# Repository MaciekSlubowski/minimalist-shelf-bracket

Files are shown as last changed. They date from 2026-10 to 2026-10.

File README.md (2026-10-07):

Minimalist Shelf Bracket

A sleek, fully parametric 3D-printable wall mount for shelves. Written in OpenSCAD, this minimalist bracket features a smooth geometric arch, clean lines, and a topology-inspired design optimized for flat, support-free FDM printing. It combines modern aesthetics with high structural integrity.
## 📷 Gallery

<p align="center">
  Assembled Shelves System
  Mounted Bracket Close-up
</p>
<p align="center">
  <i>Left: The brackets mounted on a solid wall, seamlessly supporting wooden shelf boards. Right: Close-up of the flush fit and sleek arch supporting the shelf.</i>
</p>

<p align="center">
  Printed Bracket on Table
  Cura Slicer View
</p>
<p align="center">
  <i>Left: The printed bracket showing clean layer lines and perfectly formed countersunk holes. Right: Slicer visualization demonstrating the flat, support-free print orientation.</i>
</p>

📏 Default Dimensions

Based on the default parameters in the OpenSCAD file, the generated bracket has the following specifications:

Shelf Arm (X-axis): 210 mm

Wall Arm (Y-axis): 100 mm

Frame Width: 12 mm

Total Thickness: 20 mm

Mounting Holes: Countersunk, designed for standard flat-head screws to sit completely flush with the surface.

✨ Features

Fully Parametric: Easily adjust arm lengths, frame width, arch thickness, and overall depth directly in the OpenSCAD file to fit any shelf size.

Support-Free Printing: Carefully designed to be printed completely flat on the build plate. Requires zero support structures, saving material and post-processing time.

Sleek & Minimalist: Relies on simple, unobtrusive geometry that blends perfectly into modern, Scandinavian, or industrial interiors.

## ⚙️ Key OpenSCAD Variables

The bracket is fully customizable. You can easily adapt the geometry to your specific needs by modifying the following variables at the top of the `.scad` file:

*   **`shelf_len`** (Default: `210`): The length of the horizontal arm supporting the shelf (along the X-axis).
*   **`wall_len`** (Default: `100`): The length of the vertical arm mounted to the wall (along the Y-axis).
*   **`arm_width`** (Default: `12`): The width of the solid outer frame. This determines the main structural rigidity of the bracket.
*   **`arch_thick`** (Default: `6`): The thickness of the inner geometric arch. Kept thinner than the main frame to maintain a sleek, visually lightweight aesthetic.
*   **`thickness`** (Default: `20`): The total 3D depth (Z-axis) of the printed bracket.
*   **`$fn`** (Default: `150`): The resolution parameter. Set high to ensure the geometric curves and countersunk holes render perfectly smooth.

## 🔧 Pro-Tip: Fixing Misaligned Drill Holes

Did your drill bit slip on the masonry, leaving the holes in your wall slightly too high or too low? Don't drill new holes and ruin your wall! You can easily shift the mounting holes directly on the 3D model to perfectly match the mistake on your wall. 

Just scroll down to **STEP 4: FINAL 3D MODEL GENERATION** in the OpenSCAD code and adjust the coordinates passed to the hole functions:
*   `wall_hole(-85);` ➔ Change the `-85` (Y-axis) to move the hole up or down along the wall arm.
*   `shelf_hole(170);` ➔ Change the `170` (X-axis) to shift the shelf mounting hole left or right.

🖨️ Recommended Print Settings

To ensure the bracket can safely support loads (like thick wooden boards and books) without snapping, follow these guidelines

Material: PETG or PETG-CF (Carbon Fiber) works best for superior layer adhesion, impact resistance, and slight flexibility under load. 

Layer Height: 0.20 mm - 0.24 mm. While a 0.8 mm nozzle can print thicker layers, keeping it around 0.24 mm ensures the curved organic arch remains smooth and aesthetically pleasing.

Walls/Perimeters: 4-5 walls. This is CRITICAL. The structural strength of a bracket comes primarily from its thick outer perimeters, not the infill.

Top/Bottom Thickness: ~1.4 mm (approx. 5-8 layers depending on your layer height) to ensure solid mounting points.

Infill: 20% - 25% Gyroid. The 3D gyroid pattern distributes stress evenly across all axes, perfectly complimenting the topology-optimized arch.

⚠️ Note on Hardware & Hole Tolerances

FDM plastics often shrink, and thick 0.8 mm extrusions can slightly squish into holes.

Hole Horizontal Expansion: In your slicer (e.g., Cura), set this to 0.4 mm. This compensates for the shrinkage and ensures your screws will slide in smoothly without splitting the printed layers when tightened.

Mounting Hardware: For solid walls (like silicate blocks or concrete), use high-quality 8x40 expansion anchors (e.g., Fischer SX Plus) with matching 4-5 mm flat-head screws. Do not overtighten—let the flush countersink distribute the pressure.

This project is open-source and provided strictly for personal, educational, and non-commercial purposes. You are free to explore, modify, and learn from the codebase. If you wish to use this project for commercial purposes, please contact me. Maciej Ślubowski

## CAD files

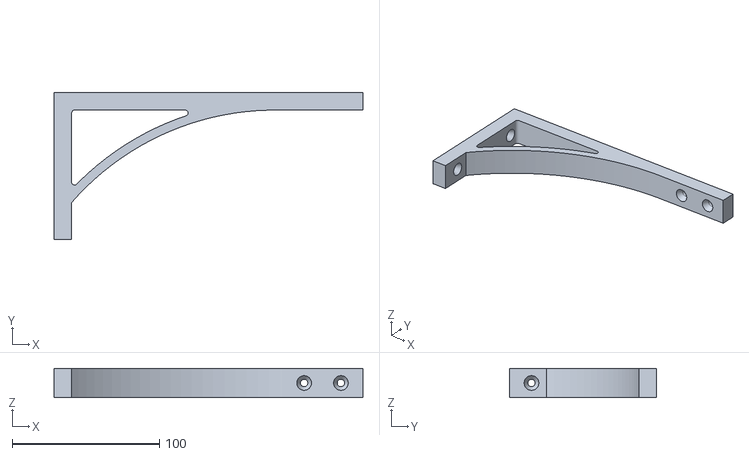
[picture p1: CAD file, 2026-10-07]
SHELF BRACKET.stl
210.0 x 100.0 x 20.0

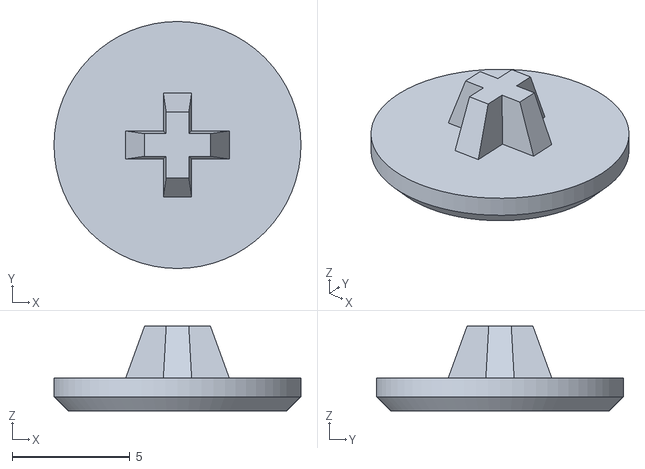
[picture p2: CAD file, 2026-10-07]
SCREW COVER.stl
10.5 x 10.5 x 3.61

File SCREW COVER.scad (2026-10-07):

// ====================================================================
// PARAMETRIC SCREW COVER / CAP (OPTIMIZED FOR 3D PRINTING)
// ====================================================================
// This script generates a customizable screw cap designed to fit directly 
// into the screw head (e.g., PZ2/PH2) or a standard hole.
// It is designed to be printed flat on the build plate without supports.
// ====================================================================
$fn = 64;

// --- MAIN CAP DIMENSIONS (VISIBLE PART) ---
cap_diameter          = 10.5; // Outer diameter of the cap (mm) - match to your screw head or countersink
cap_thickness         = 1.4;  // Thickness of the visible cap cover (mm)
edge_chamfer          = 0.6;  // Chamfer/radius on the top outer edge (mm) for a smooth look

// --- MOUNTING STEM TYPE SELECTION ---
// "cross" - 4-blade wedge pressed directly into a PZ/PH screw drive
// "plug"  - Slightly tapered solid cylinder pressed into a stripped or round hole
mount_type            = "cross"; // ["cross", "plug"]

// --- CROSS MOUNT PARAMETERS (Default: PZ2) ---
cross_length          = 2.2;  // Insertion depth into the screw drive (mm)
cross_span_base       = 4.4;  // Total span of the blades at the base (mm)
cross_span_tip        = 2.8;  // Total span of the blades at the tip (mm)
cross_blade_thickness = 1.2;  // Thickness of a single cross blade (mm)

// --- PLUG MOUNT PARAMETERS (Alternative for thick nozzles / stripped screws) ---
plug_diameter_base    = 4.6;  // Diameter at the base/cap connection (mm)
plug_diameter_tip     = 3.8;  // Diameter at the insertion tip (mm)
plug_length           = 2.2;  // Total length of the plug (mm)

// ====================================================================
// MODEL GEOMETRY
// ====================================================================

// Generates the flat, visible part of the cap with a chamfered top edge
module cap_face() {
    hull() {
        cylinder(r = (cap_diameter / 2) - edge_chamfer, h = cap_thickness);
        translate([0, 0, edge_chamfer])
            cylinder(r = cap_diameter / 2, h = cap_thickness - edge_chamfer);
    }
}

// Generates a single tapered blade for the cross mount
module cross_blade(length, span_bottom, span_top, thick_bottom, thick_top) {
    hull() {
        cube([span_bottom, thick_bottom, 0.01], center = true);
        translate([0, 0, length])
            cube([span_top, thick_top, 0.01], center = true);
    }
}

// Combines two perpendicular blades to form the Phillips/Pozidriv cross
module cross_stem() {
    translate([0, 0, cap_thickness]) {
        cross_blade(cross_length, cross_span_base, cross_span_tip, cross_blade_thickness, cross_blade_thickness * 0.8);
        cross_blade(cross_length, cross_blade_thickness, cross_blade_thickness * 0.8, cross_span_base, cross_span_tip);
    }
}

// Generates the alternative tapered solid plug
module plug_stem() {
    translate([0, 0, cap_thickness])
        cylinder(d1 = plug_diameter_base, d2 = plug_diameter_tip, h = plug_length);
}

// ====================================================================
// FINAL ASSEMBLY
// ====================================================================
union() {
    // Render the main visible cap
    cap_face();
    
    // Render the chosen mounting mechanism
    if (mount_type == "cross") {
        cross_stem();
    } else if (mount_type == "plug") {
        plug_stem();
    }
}

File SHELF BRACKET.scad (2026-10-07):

// ====================================================================
// MINIMALIST SHELF BRACKET - PARAMETRIC MODEL
// ====================================================================
// This script generates a sleek, minimalist shelf bracket.
// It is designed to be printed flat on the print bed without supports.
// ====================================================================

// --- BRACKET PARAMETERS ---
shelf_len = 210;         // Length of the horizontal arm supporting the shelf (X-axis)
wall_len = 100;          // Length of the vertical arm mounted to the wall (Y-axis)
arm_width = 12;          // Width of the solid outer frame/arms (mm)
arch_thick = 6;          // Thickness of the inner geometric arch (mm)
thickness = 20;          // Total 3D thickness (Z-axis) of the bracket (mm)
$fn = 150;               // High resolution for smooth curves and arcs

// ====================================================================
// STEP 1: BASE 2D SHAPE (Solid frame with a smooth geometric arch)
// ====================================================================
module solid_base() {
    union() {
        // Solid outer frame (ensures a strict 12mm width on both arms)
        polygon([
            [0, 0],
            [shelf_len, 0],
            [shelf_len, -arm_width],
            [arm_width, -arm_width],
            [arm_width, -wall_len],
            [0, -wall_len]
        ]);
        
        // Optimized, long, and smooth supporting arch
        difference() {
            // Rough triangular bounding box for the arch
            polygon([
                [arm_width, -arm_width],
                [155, -arm_width],
                [arm_width, -190] 
            ]);
            // Mathematically calculated cutting circle to create the sleek curve
            translate([150, -195]) circle(r=183);
        }
    }
}

// ====================================================================
// STEP 2: INNER WINDOW (Smooth cutout to form the arch)
// ====================================================================
module inner_window() {
    // The offset(r=2) offset(r=-2) trick rounds sharp internal corners.
    // This acts as a crucial stress relief mechanism to prevent cracking under heavy loads.
    offset(r=2) offset(r=-2)
    difference() {
        // Inner profile protecting the 12mm solid frame
        polygon([
            [arm_width, -arm_width], 
            [105, -arm_width], 
            [arm_width, -120]
        ]);
        
        // The exact same cutting circle from step 1, but expanded by the arch thickness (6mm)
        translate([150, -195]) circle(r=183 + arch_thick);
    }
}

// ====================================================================
// STEP 3: MOUNTING HOLES (Countersunk for a flush flat-head screw fit)
// ====================================================================
module wall_hole(y_pos) {
    // Drilled horizontally along the X-axis (from the inner face towards the wall)
    translate([arm_width + 0.01, y_pos, thickness / 2])
    rotate([0, -90, 0]) {
        cylinder(r=2.5, h=arm_width + 2, $fn=32);              // Clearance hole for the screw shaft (5mm diameter)
        cylinder(r1=5.0, r2=2.5, h=4.5, $fn=32);               // Countersink for the screw head to sit completely flush
    }
}

module shelf_hole(x_pos) {
    // Drilled vertically along the Y-axis (from the inner face towards the shelf)
    translate([x_pos, -arm_width - 0.01, thickness / 2])
    rotate([-90, 0, 0]) {
        cylinder(r=2.5, h=arm_width + 2, $fn=32);              // Clearance hole for the screw shaft (5mm diameter)
        cylinder(r1=5.0, r2=2.5, h=4.5, $fn=32);               // Countersink for the screw head to sit completely flush
    }
}

// ====================================================================
// STEP 4: FINAL 3D MODEL GENERATION
// ====================================================================
difference() {
    // 1. Extrude the 2D profile into a 3D solid
    linear_extrude(height = thickness)
    difference() {
        solid_base();
        inner_window();
    }
    
    // 2. Cut out wall mounting holes (using negative Y coordinates)
    wall_hole(-85); 
    wall_hole(-20); 

    // 3. Cut out shelf mounting holes (using positive X coordinates)
    shelf_hole(170); 
    shelf_hole(195); 
}

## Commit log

2026-10-07 Refactor shelf bracket SCAD code with comments
    Updated the shelf bracket model with enhanced comments and structure.
    [SHELF BRACKET.scad]
2026-10-07 Enhance README with pro-tip for drill hole alignment
    Added pro-tip for fixing misaligned drill holes in README.
2026-10-07 Update README with print settings section
    Added recommended print settings for bracket support.
